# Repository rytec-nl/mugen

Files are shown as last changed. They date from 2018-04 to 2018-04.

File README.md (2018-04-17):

# Mugen, my implementation

This project is born because I wanted to connect an external amplifier to my Samsung smart tv that fits my tv cabinet.
The obvious step was to build a hybrid tube/transistor amplifier myself. I was pointed to the Mugen hybrid amplifier. It fit my size and power requirements (I have 2 60W Visaton speakers). Altough there were some things that need to be added for it to work with my setup. 

For one i want to use my tv remote to change the volume, so I will need to implement a IR reciever that controls a variable resistor in the input signal. This means an additional power supply, a microcontroller to process the IR signals and control a digital potentiometer. 

The next challenge is that my TV only has an optical audio out, so I need to hook up a optical to aux convertor. My plan as of now is to buy the smallest I can find and build it into the amplifier. If this proves impossible, it will stay as an external box. 

Finally I want the amplifier to look good. So I am planning to change the design to have both tubes above eachother when facing the front of the amplifier. I can then place a see through window in front of the Tubes so they can be seen. Then hookup some LEDs to the microcontroller, and place them behind the tubes for some cool effects. Using the Microcontroller I can the dim the LEDs using a PWM signal. This all being carefull not to let the PWM signal interfere with the audio signal.

## Additions

As I'm working on the amplifier the design is improving. Instead of using plain windows in front of the tubes, the idea now is to use LCD displays where the backlight is removed. This gives a transparent view inside the amplifier when nothing is displayed. When needed lights inside the amp. will light up, and whatever is shown on the LCD becomes visible. This will be used for volume indication. 

In order for this to be implemented, in stead of simply adding a power supply to the main power board, a completely extra PCB will be added for the logic needed. 

## Todo

- [ ] Power Supply
   - [x] original schematic
   - [ ] schematic review 
   - [x] PCB
   - [ ] PCB review 
- [ ] Amplifier
   - [x] schematic 
   - [ ] schematic review
   - [ ] PCB
   - [ ] PCB review
- [ ] Logic board
   - [ ] schematic 
   - [ ] schematic review
   - [ ] PCB
   - [ ] PCB review
- [ ] Case
   - [ ] Front
      - [ ] design
      - [ ] build
   - [ ] back
      - [ ] design
      - [ ] build
   - [ ] bottom/top
   - [ ] sides
 - [ ] Firmware
    - [x] IR reciever test
    - [ ] IR reciever
    - [ ] Volume control
    - [ ] LED PWM
    - [ ] LED Level Control
    - [x] LCD control test
    - [ ] LCD control

## KiCad

The PCBs are designed using [KiCad](http://kicad-pcb.org/). This is the most usable free PCB design software I could find, that also works on Linux. Before this project I normally would use [Eagle](https://www.autodesk.com/products/eagle/overview), I even started this project using Eagle. But for me it is just to expensive for boards larger than `160mm x 100mm` ($65/month or in my case €85/month). So I chose a free alternative, that so far I am liking very much!

## Power Supply

### Schematic & PCB



### 3D View

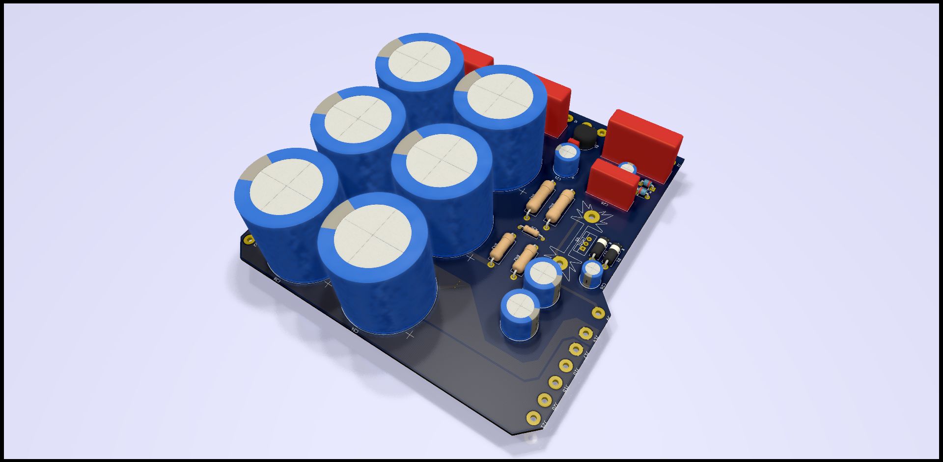
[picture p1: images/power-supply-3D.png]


## Amplifier

### Schematic & PCB



### 3D View

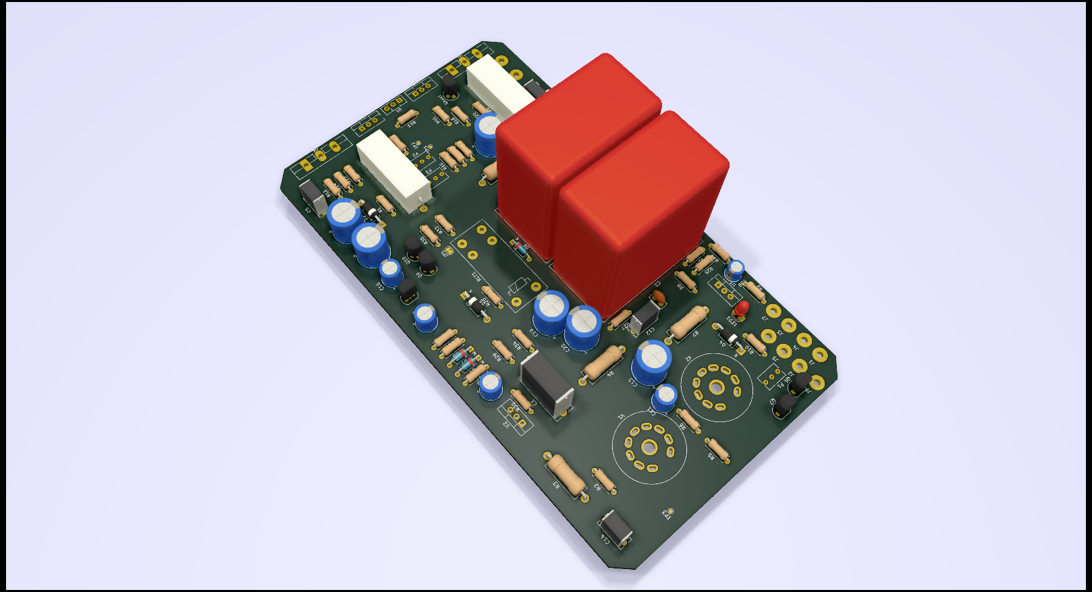
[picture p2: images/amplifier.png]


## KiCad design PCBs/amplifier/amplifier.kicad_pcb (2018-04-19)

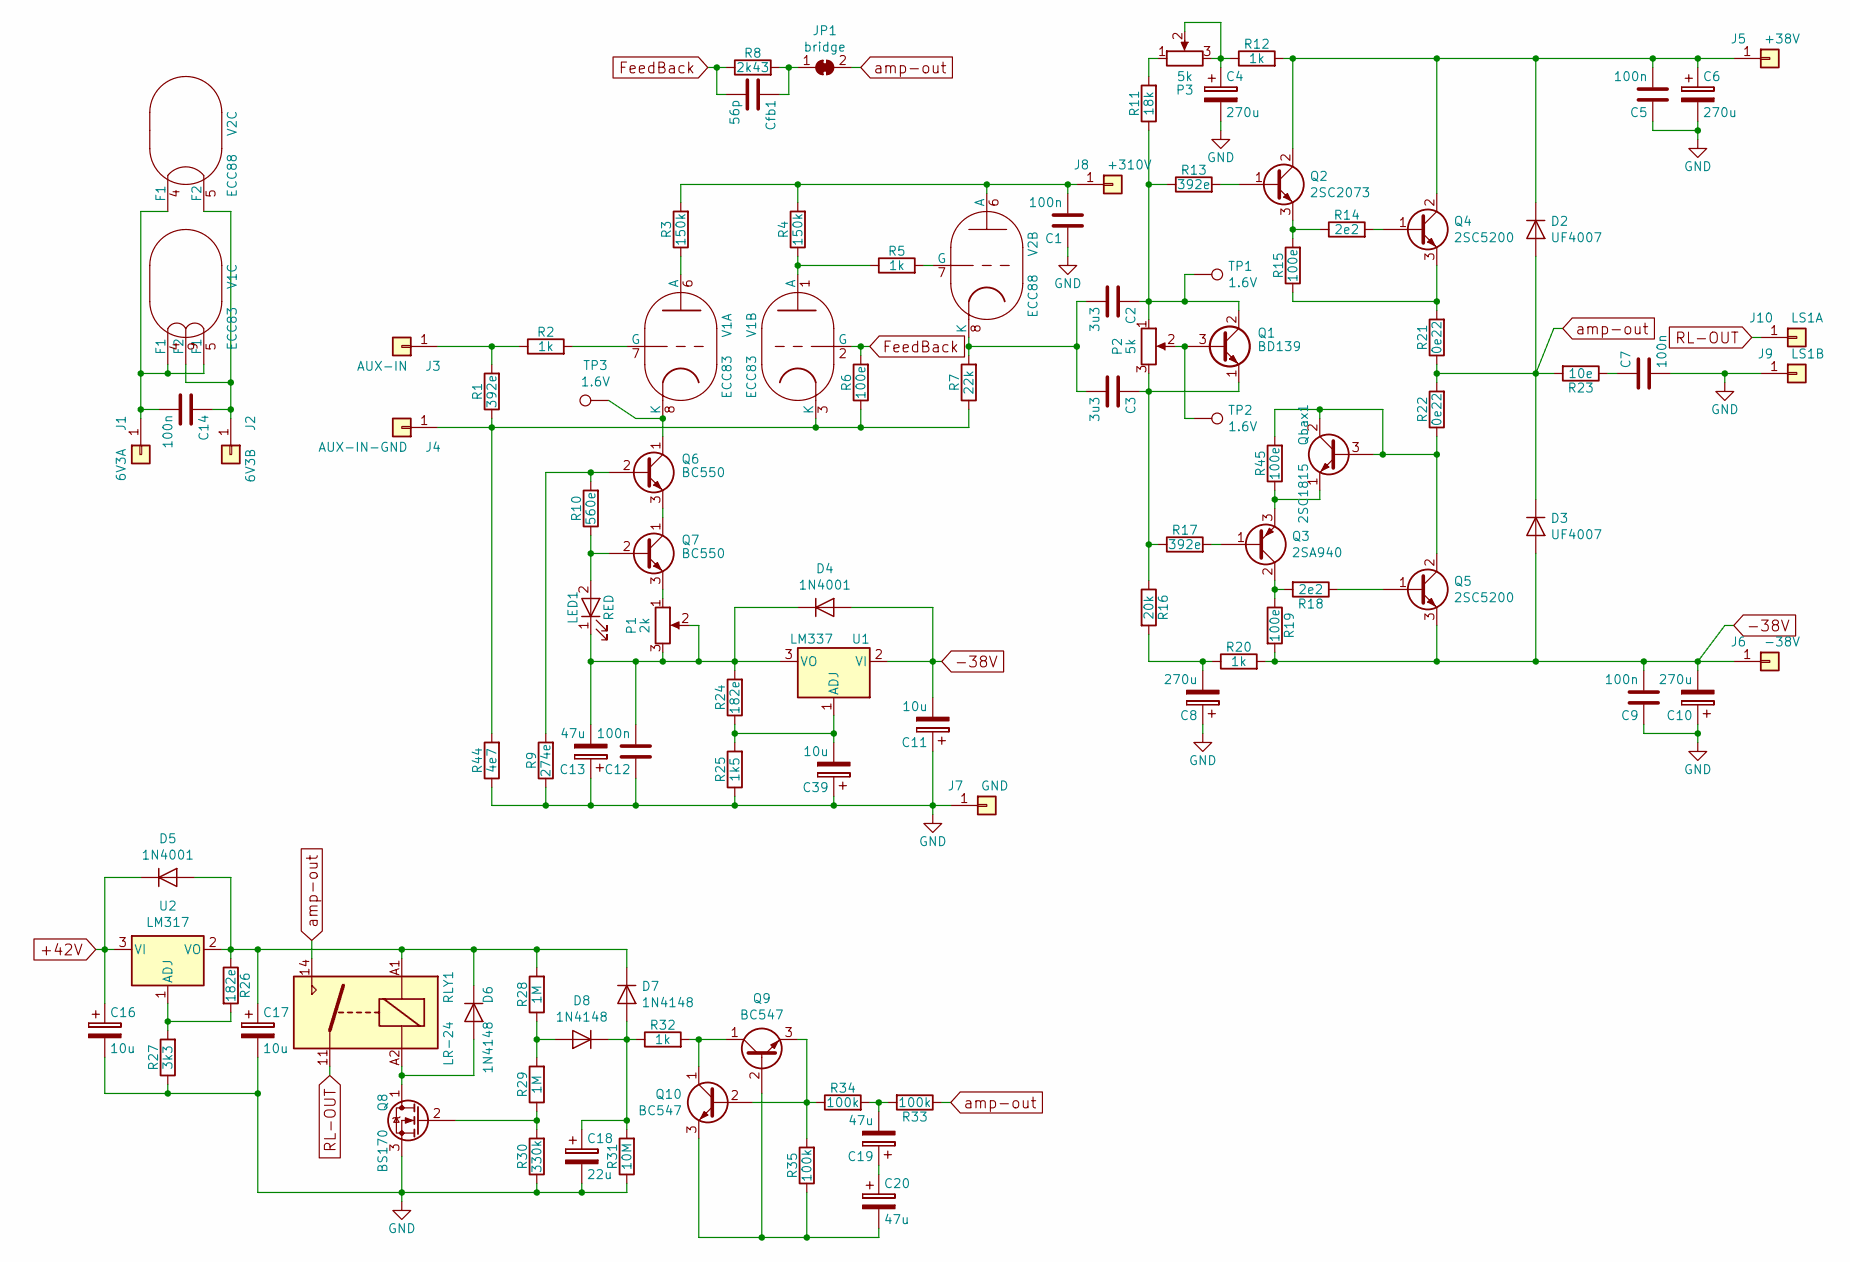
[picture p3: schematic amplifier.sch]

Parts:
C1: 100n; C_Rect_L16.5mm_W6.0mm_P15.00mm_MKT
C2, C3: 3u3; C_Rect_L41.5mm_W24.0mm_P37.50mm_MKS4
C4, C6, C8, C10: 270u; CP_Radial_D10.0mm_P3.80mm
C5, C9, C12, C14: 100n; C_Rect_L9.0mm_W3.8mm_P7.50mm_MKT
C7: 100n; C_Rect_L7.2mm_W5.5mm_P5.00mm_FKS2_FKP2_MKS2_MKP2
C11, C16, C17: 10u; CP_Radial_D6.3mm_P2.50mm
C13, C19, C20: 47u; CP_Radial_D10.0mm_P5.00mm
C18: 22u; CP_Radial_D6.3mm_P2.50mm
C39: 10u; CP_Radial_D5.0mm_P2.00mm
Cfb1: 56p; C_Disc_D5.0mm_W2.5mm_P2.50mm
D2, D3: UF4007; D_DO-41_SOD81_P10.16mm_Horizontal
D4, D5: 1N4001; D_DO-41_SOD81_P10.16mm_Horizontal
D6, D7, D8: 1N4148; D_DO-35_SOD27_P7.62mm_Horizontal
J1: 6V3A; SolderWirePad_single_2mmDrill
J2: 6V3B; SolderWirePad_single_2mmDrill
J3: AUX-IN; SolderWirePad_single_2mmDrill
J4: AUX-IN-GND; SolderWirePad_single_2mmDrill
J5: +38V; SolderWirePad_single_2mmDrill
J6: -38V; SolderWirePad_single_2mmDrill
J7: GND; SolderWirePad_single_2mmDrill
J8: +310V; SolderWirePad_single_2mmDrill
J9: LS1B; SolderWirePad_single_2mmDrill
J10: LS1A; SolderWirePad_single_2mmDrill
JP1: bridge; SolderJumper-2_P1.3mm_Bridged_RoundedPad1.0x1.5mm
LED1: RED; LED_D3.0mm
P1: 2k; Potentiometer_Bourns_3266Y_Vertical
P2, P3: 5k; Potentiometer_Bourns_3266Y_Vertical
Q1: BD139; TO-126_Vertical
Q2: 2SC2073; TO-220-3_Vertical
Q3: 2SA940; TO-220-3_Vertical
Q4, Q5: 2SC5200; TO-264_Vertical
Q6, Q7: BC550; TO-92
Q8: BS170; TO-92_Inline
Q9, Q10: BC547; TO-92
Qbax1: 2SC1815; TO-92
R1, R13, R17: 392e; R_Axial_DIN0207_L6.3mm_D2.5mm_P7.62mm_Horizontal
R2, R5, R12, R20, R32: 1k; R_Axial_DIN0207_L6.3mm_D2.5mm_P7.62mm_Horizontal
R3, R4: 150k; R_Axial_DIN0414_L11.9mm_D4.5mm_P15.24mm_Horizontal
R6, R15, R19, R45: 100e; R_Axial_DIN0207_L6.3mm_D2.5mm_P7.62mm_Horizontal
R7: 22k; R_Axial_DIN0414_L11.9mm_D4.5mm_P15.24mm_Horizontal
R8: 2k43; R_Axial_DIN0207_L6.3mm_D2.5mm_P7.62mm_Horizontal
R9: 274e; R_Axial_DIN0207_L6.3mm_D2.5mm_P7.62mm_Horizontal
R10: 560e; R_Axial_DIN0207_L6.3mm_D2.5mm_P7.62mm_Horizontal
R11: 18k; R_Axial_DIN0207_L6.3mm_D2.5mm_P7.62mm_Horizontal
R14, R18: 2e2; R_Axial_DIN0207_L6.3mm_D2.5mm_P7.62mm_Horizontal
R16: 20k; R_Axial_DIN0207_L6.3mm_D2.5mm_P7.62mm_Horizontal
R21, R22: 0e22; R_Axial_Power_L25.0mm_W9.0mm_P27.94mm
R23: 10e; R_Axial_DIN0414_L11.9mm_D4.5mm_P15.24mm_Horizontal
R24, R26: 182e; R_Axial_DIN0207_L6.3mm_D2.5mm_P7.62mm_Horizontal
R25: 1k5; R_Axial_DIN0207_L6.3mm_D2.5mm_P7.62mm_Horizontal
R27: 3k3; R_Axial_DIN0207_L6.3mm_D2.5mm_P7.62mm_Horizontal
R28, R29: 1M; R_Axial_DIN0207_L6.3mm_D2.5mm_P7.62mm_Horizontal
R30: 330k; R_Axial_DIN0207_L6.3mm_D2.5mm_P7.62mm_Horizontal
R31: 10M; R_Axial_DIN0207_L6.3mm_D2.5mm_P7.62mm_Horizontal
R33, R34, R35: 100k; R_Axial_DIN0207_L6.3mm_D2.5mm_P7.62mm_Horizontal
R44: 4e7; R_Axial_DIN0207_L6.3mm_D2.5mm_P7.62mm_Horizontal
RLY1: LR-24; Relay_SPST_Schrack-RP-II-1-16A-FormA_RM5mm
TP1, TP2, TP3: 1.6V; TestPoint_Pad_D1.0mm
U1: LM337; TO-220-3_Vertical
U2: LM317; TO-220-3_Vertical
V1: ECC83; Valve_ECC-83-2
V2: ECC88; Valve_ECC-83-2

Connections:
+42V: C16.1, D5.1 (K), U2.3 (VI)
-38V: C9.2, C10.2, C11.2, D3.2 (A), D4.2 (A), J6.1, Q5.3 (E), R19.2, R20.2, U1.2 (VI)
FeedBack: Cfb1.2, R6.2, R8.1, V1.2 (G)
GND: C1.1, C4.2, C5.1, C6.2, C7.2, C8.1, C9.1, C10.1, C11.1, C12.1, C13.1, C16.2, C17.2, C18.2, C39.1, J7.1, J9.1, Q8.3 (S), R9.1, R25.1, R27.1, R30.1, R31.1, R44.1
unnamed: C1.2, J8.1, R3.2, R4.2, V2.6 (A)
unnamed: C2.1, P2.1, Q1.2 (C), R11.1, R13.1, TP1.1
unnamed: C2.2, C3.2, R7.2, V2.8 (K)
unnamed: C3.1, P2.3, Q1.1 (E), R16.1, R17.1
unnamed: C4.1, P3.2, P3.3, R12.1
unnamed: C5.2, C6.1, D2.1 (K), J5.1, Q2.2 (C), Q4.2 (C), R12.2
unnamed: C7.1, R23.1
unnamed: C8.2, R16.2, R20.1
unnamed: C12.2, C13.2, D4.1 (K), LED1.1 (K), P1.2, P1.3, R24.2, U1.3 (VO)
unnamed: C14.1, J2.1, V1.9 (F2), V2.5 (F2)
unnamed: C14.2, J1.1, V1.4 (F1), V1.5 (F1), V2.4 (F1)
unnamed: C17.1, D5.2 (A), D6.1 (K), D7.1 (K), R26.1, R28.2, RLY1.A1, U2.2 (VO)
unnamed: C18.1, D7.2 (A), D8.1 (K), R31.2, R32.1
unnamed: C19.1, C20.1
unnamed: C19.2, R33.2, R34.2
unnamed: C20.2, Q9.2 (B), Q10.3 (E), R35.1
unnamed: C39.2, R24.1, R25.2, U1.1 (ADJ)
unnamed: Cfb1.1, JP1.1 (A), R8.2
unnamed: D6.2 (A), Q8.1 (D), RLY1.A2
unnamed: D8.2 (A), R28.1, R29.2
unnamed: J3.1, R1.2, R2.1
unnamed: J4.1, R1.1, R6.1, R7.1, R44.2, V1.3 (K)
unnamed: LED1.2 (A), Q7.2 (B), R10.1
unnamed: P1.1, Q7.3 (E)
unnamed: P2.2, Q1.3 (B), TP2.1
unnamed: P3.1, R11.2
unnamed: Q2.1 (B), R13.2
unnamed: Q2.3 (E), R14.1, R15.2
unnamed: Q3.1 (B), R17.2
unnamed: Q3.2 (C), R18.2, R19.1
unnamed: Q3.3 (E), Qbax1.1 (E), R45.1
unnamed: Q4.1 (B), R14.2
unnamed: Q4.3 (E), R15.1, R21.2
unnamed: Q5.1 (B), R18.1
unnamed: Q5.2 (C), Qbax1.2 (C), Qbax1.3 (B), R22.1, R45.2
unnamed: Q6.1 (C), TP3.1, V1.8 (K)
unnamed: Q6.2 (B), R9.2, R10.2
unnamed: Q6.3 (E), Q7.1 (C)
unnamed: Q8.2 (G), R29.1, R30.2
unnamed: Q9.1 (C), Q10.1 (C), R32.2
unnamed: Q9.3 (E), Q10.2 (B), R34.1, R35.2
unnamed: R2.2, V1.7 (G)
unnamed: R3.1, V1.6 (A)
unnamed: R4.1, R5.1, V1.1 (A)
unnamed: R5.2, V2.7 (G)
unnamed: R26.2, R27.2, U2.1 (ADJ)
RL-OUT: J10.1, RLY1.11
amp-out: D2.2 (A), D3.1 (K), JP1.2 (B), R21.1, R22.2, R23.2, R33.1, RLY1.14

Board: 2 copper layers, 99 parts (0 on the bottom side), 52 nets, no tracks yet.

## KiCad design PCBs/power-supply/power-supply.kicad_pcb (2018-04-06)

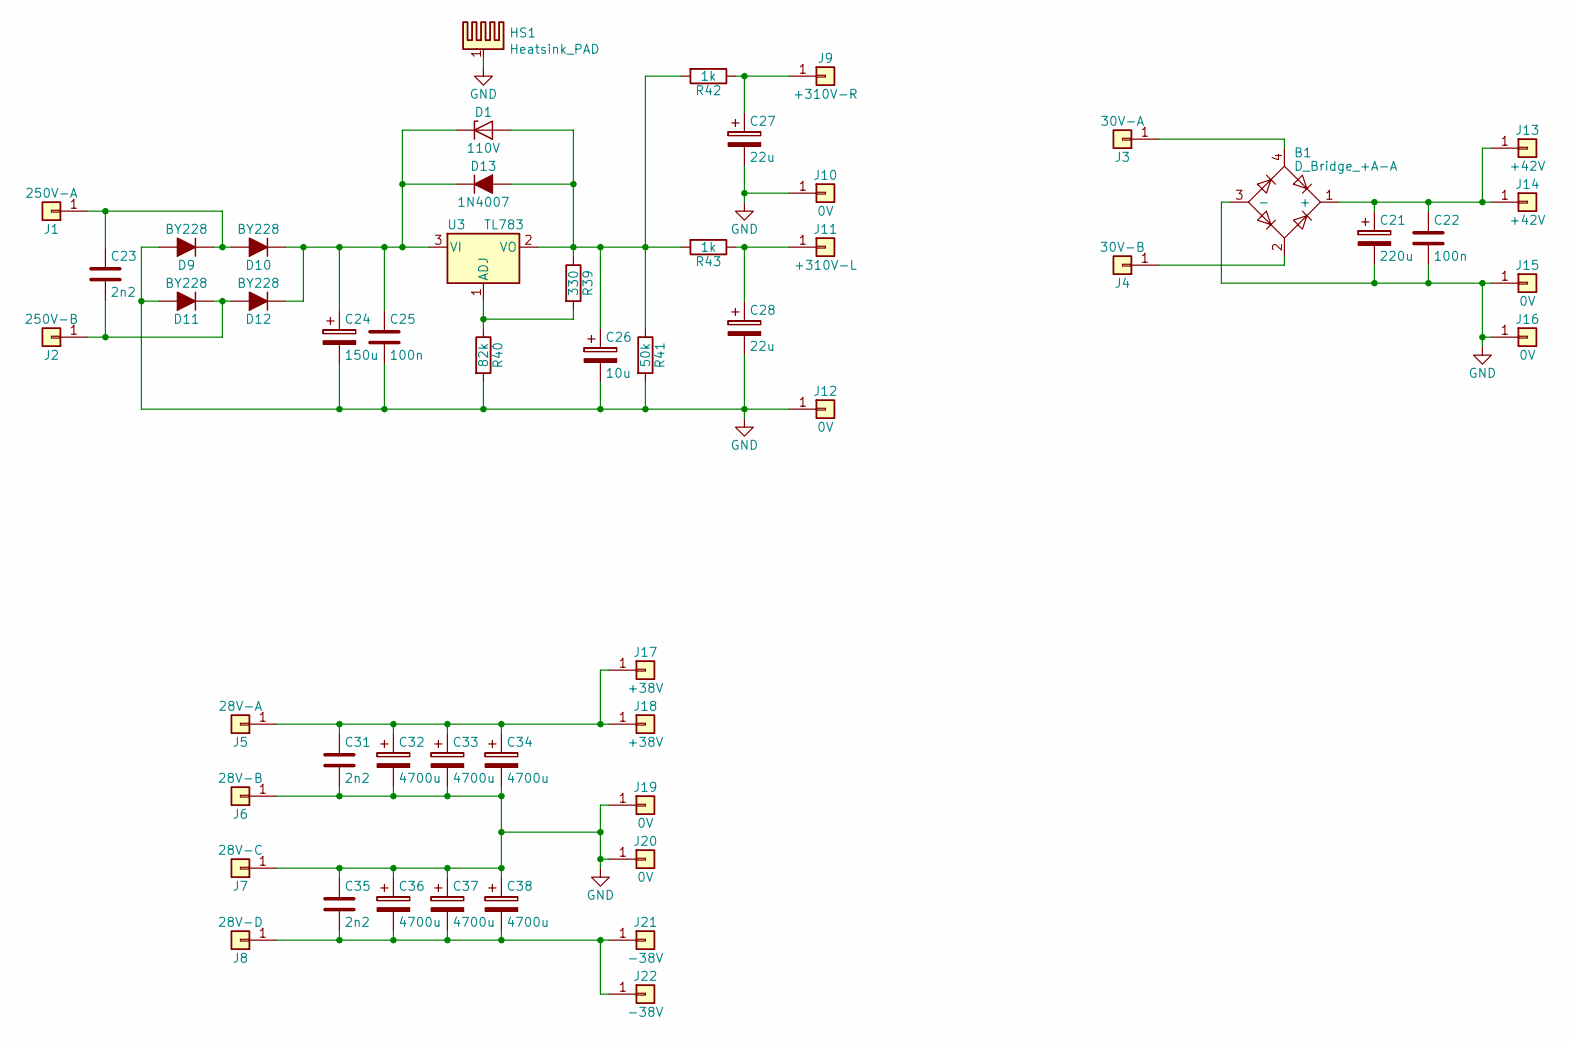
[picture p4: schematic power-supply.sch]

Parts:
B1: D_Bridge_+A-A; Diode_Bridge_Round_D9.8mm
C21: 220u; CP_Radial_D10.0mm_P3.80mm
C22: 100n; C_Rect_L4.6mm_W2.0mm_P2.50mm_MKS02_FKP02
C23: 2n2; C_Rect_L28.0mm_W8.0mm_P22.50mm_MKS4
C24: 150u; CP_Radial_D7.5mm_P2.50mm
C25: 100n; C_Rect_L18.0mm_W6.0mm_P15.00mm_FKS3_FKP3
C26: 10u; CP_Radial_D7.5mm_P2.50mm
C27, C28: 22u; CP_Radial_D13.0mm_P5.00mm
C31, C35: 2n2; C_Rect_L27.0mm_W9.0mm_P23.00mm
C32, C33, C34, C36, C37, C38: 4700u; CP_Radial_D35.0mm_P10.00mm_SnapIn
D1: 110V; D_DO-15_P10.16mm_Horizontal
D9, D10, D11, D12: BY228; D_T-1_P5.08mm_Horizontal
D13: 1N4007; D_DO-15_P10.16mm_Horizontal
HS1: Heatsink_PAD; Heatsink_Fischer_SK104-STC-STIC_35x13mm_2xDrill2.5mm
J1: 250V-A; SolderWirePad_single_2mmDrill
J2: 250V-B; SolderWirePad_single_2mmDrill
J3: 30V-A; SolderWirePad_single_2mmDrill
J4: 30V-B; SolderWirePad_single_2mmDrill
J5: 28V-A; SolderWirePad_single_2mmDrill
J6: 28V-B; SolderWirePad_single_2mmDrill
J7: 28V-C; SolderWirePad_single_2mmDrill
J8: 28V-D; SolderWirePad_single_2mmDrill
J9: +310V-R; SolderWirePad_single_2mmDrill
J10, J12, J15, J16, J19, J20: 0V; SolderWirePad_single_2mmDrill
J11: +310V-L; SolderWirePad_single_2mmDrill
J13, J14: +42V; SolderWirePad_single_2mmDrill
J17, J18: +38V; SolderWirePad_single_2mmDrill
J21, J22: -38V; SolderWirePad_single_2mmDrill
R39: 330; R_Axial_DIN0207_L6.3mm_D2.5mm_P10.16mm_Horizontal
R40: 82k; R_Axial_DIN0516_L15.5mm_D5.0mm_P20.32mm_Horizontal
R41: 50k; R_Axial_DIN0516_L15.5mm_D5.0mm_P20.32mm_Horizontal
R42, R43: 1k; R_Axial_DIN0414_L11.9mm_D4.5mm_P15.24mm_Horizontal
U3: TL783; TO-220-3_Vertical

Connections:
GND: B1.3 (-), C21.2, C22.2, C24.2, C25.2, C26.2, C27.2, C28.2, C31.2, C32.2, C33.2, C34.2, C35.1, C36.1, C37.1, C38.1, D9.2 (A), D11.2 (A), HS1.1, J6.1, J7.1, J10.1, J12.1, J15.1, J16.1, J19.1, J20.1, R40.2, R41.2
unnamed: B1.1 (+), C21.1, C22.1, J13.1, J14.1
unnamed: B1.2, J4.1
unnamed: B1.4, J3.1
unnamed: C23.1, D9.1 (K), D10.2 (A), J1.1
unnamed: C23.2, D11.1 (K), D12.2 (A), J2.1
unnamed: C24.1, C25.1, D1.1 (K), D10.1 (K), D12.1 (K), D13.1 (K), U3.3 (VI)
unnamed: C26.1, D1.2 (A), D13.2 (A), R39.1, R41.1, R42.2, R43.2, U3.2 (VO)
unnamed: C27.1, J9.1, R42.1
unnamed: C28.1, J11.1, R43.1
unnamed: C31.1, C32.1, C33.1, C34.1, J5.1, J17.1, J18.1
unnamed: C35.2, C36.2, C37.2, C38.2, J8.1, J21.1, J22.1
unnamed: R39.2, R40.1, U3.1 (ADJ)

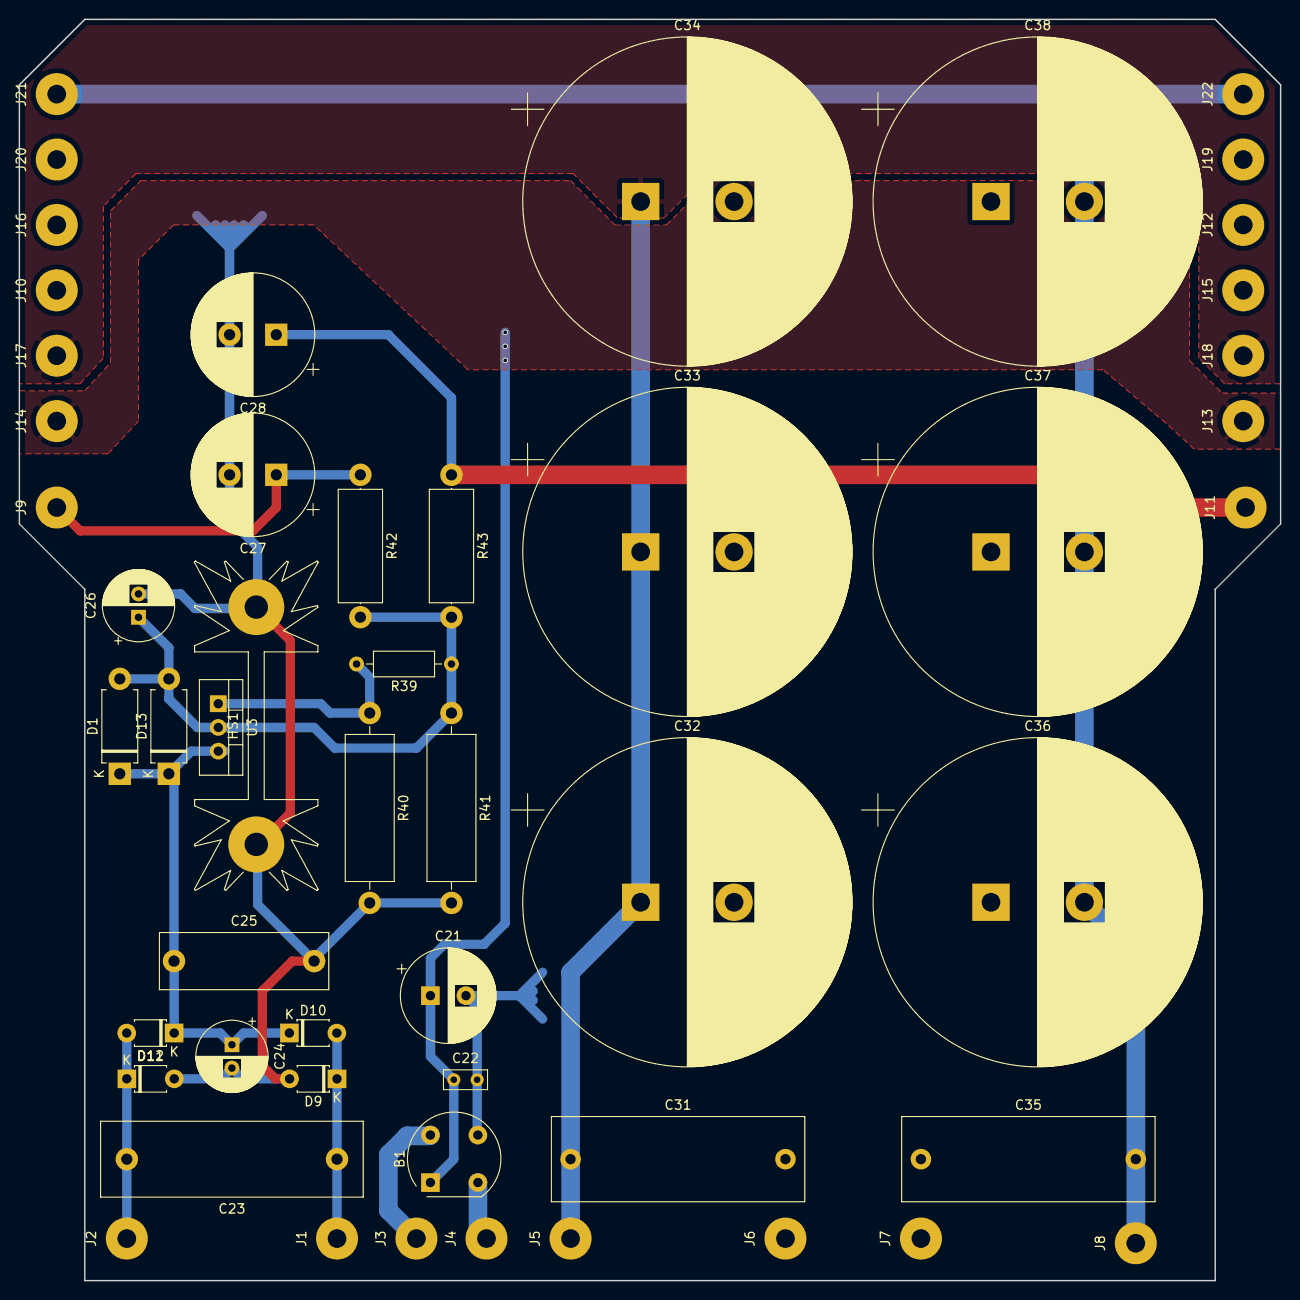
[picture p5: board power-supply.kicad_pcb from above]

Board: 2 copper layers, 135.0 x 135.0 mm, 52 parts (0 on the bottom side), 13 nets.

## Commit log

2018-03-23 Initial commit.
    [power-supply.brd, power-supply.sch]
2018-03-23 added some structure.
    [power-supply.brd, power-supply.sch]
2018-03-24 Started amp.
    [amplifier.brd, amplifier.sch, power-supply.brd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]
2018-03-24 Basic design done.
    [power-supply.brd, power-supply.sch]
2018-03-24 Added power supply image.
2018-03-27 Created kicad project.
    [amplifier.brd, amplifier.kicad_pcb, amplifier.sch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]
2018-03-27 Started on power supply in kicad.
2018-03-28 First kicad version of power supply .
    [power-supply.kicad_pcb, power-supply.sch]
2018-03-29 Small change.
    [power-supply.kicad_pcb, power-supply.sch]
2018-04-02 Started on amplifier pcb .
    [amplifier.sch, power-supply.kicad_pcb]
2018-04-02 Added image.
    [amplifier.sch]
2018-04-05 updated to kicad 5.
    [amplifier.sch]
2018-04-06 Changed footprints to kicad 5 names.
    [power-supply.kicad_pcb, power-supply.sch]
2018-04-13 fixed schematic.
    [amplifier.sch]
2018-04-13 Raw finish of amp. schematic.
    [amplifier.sch]
2018-04-13 Crude start of pcb.
    [amplifier.kicad_pcb, amplifier.sch]
2018-04-15 Fixed power-supply schematic.
    [amplifier.kicad_pcb, power-supply.sch]
2018-04-15 Added correct annotation and started assigning footprints.
    [amplifier.kicad_pcb, amplifier.sch]
2018-04-15 Updated PCB image.
2018-04-17 amp. sch. done, all footprints added.
    [amplifier.kicad_pcb, amplifier.sch]
2018-04-19 Rough component placement amp. pcb.
    [amplifier.kicad_pcb, amplifier.sch]
